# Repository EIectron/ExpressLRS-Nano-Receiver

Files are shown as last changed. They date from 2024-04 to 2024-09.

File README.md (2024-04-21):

<div align="center">
  <b>
   <h1>
      ExpressLRS micro
   </h1>
   <h6>
     V1
   </h6>
  </b>

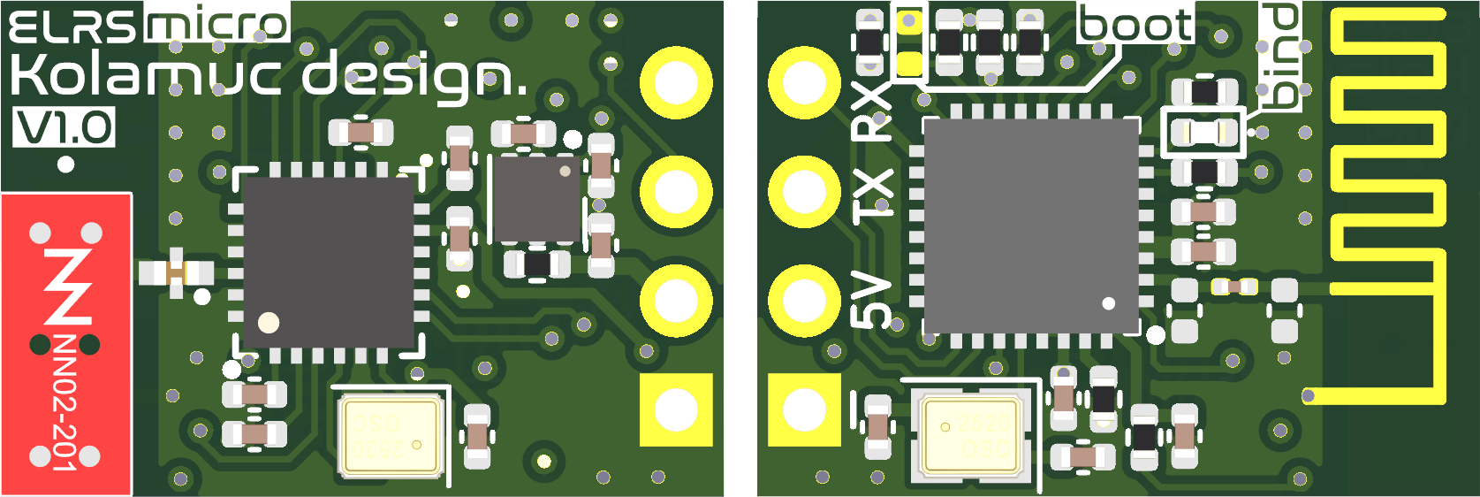
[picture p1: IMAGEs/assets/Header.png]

</div>

*Features*
* **Size**: 17x12mm
* **Gain**: 3.2dBi
* **Radio Efficiency**: >80%
* **Recommend Drone**: Whoop Drone
* **Range**: About 600 meters
* **Input voltage**: 5V
* **MCU**: ESP8285
* **Antenna**: Integrated SMD ceramic antenna
* **Frequency bands (Nano receiver 2.4G version)**: 2.4GHz ISM
* **Telemetry power**: 17mW
* *`DIY_2400_RX_ESP8285_SX1280_via_UART`*

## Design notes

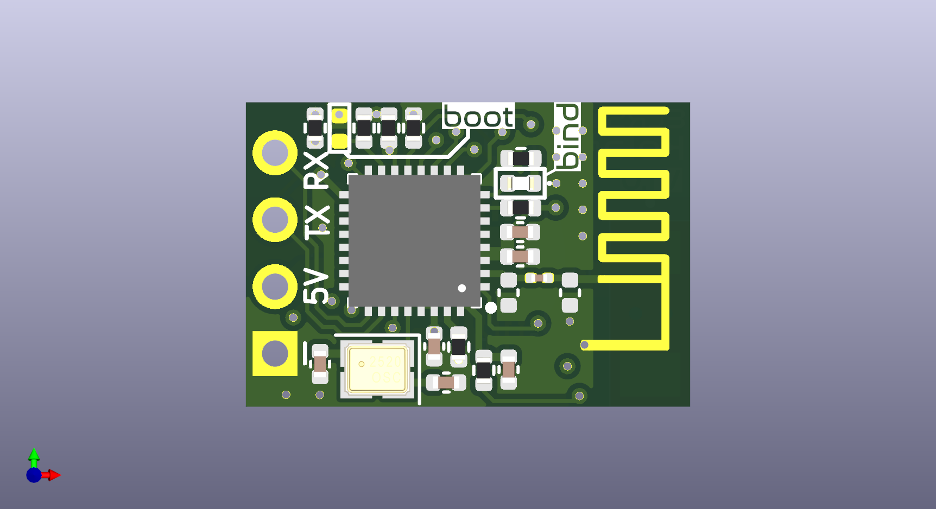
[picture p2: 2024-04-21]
IMAGEs/ExpressLRS-Nano-Receiver2.png

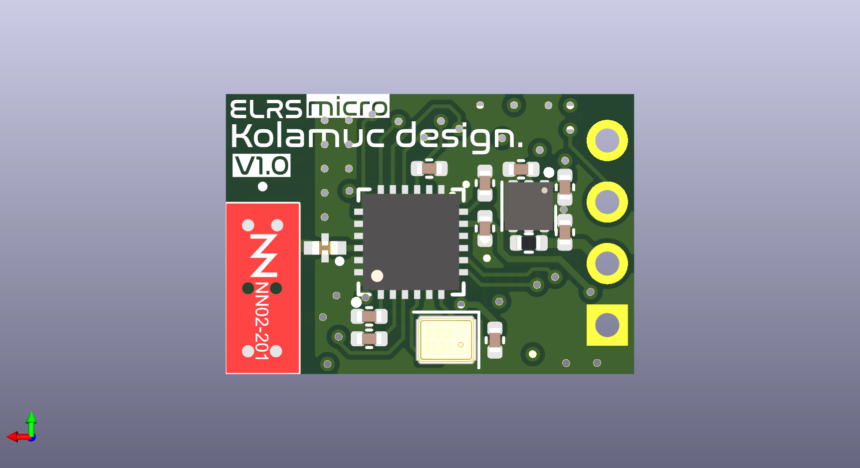
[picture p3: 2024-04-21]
IMAGEs/ExpressLRS-Nano-Receiver.png

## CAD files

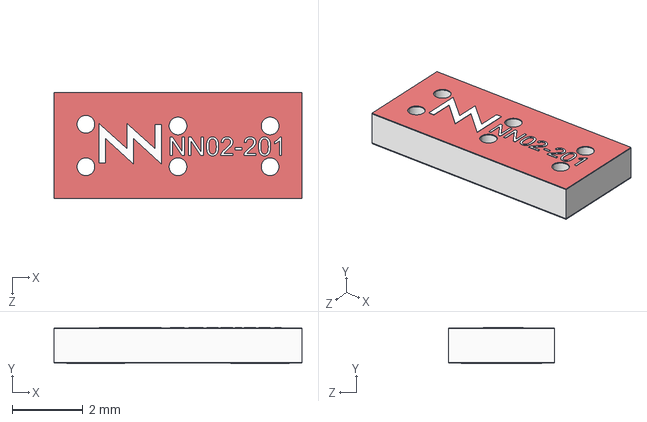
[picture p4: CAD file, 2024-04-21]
3D/NN02-201.step
7.00 x 1.02 x 3.00 mm

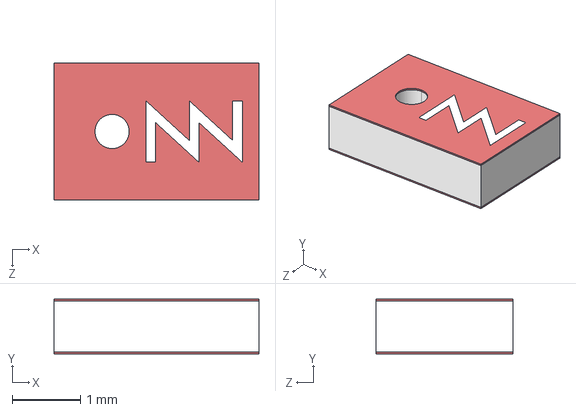
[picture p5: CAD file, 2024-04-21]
3D/NN02-101.step
3.00 x 0.8 x 2.00 mm

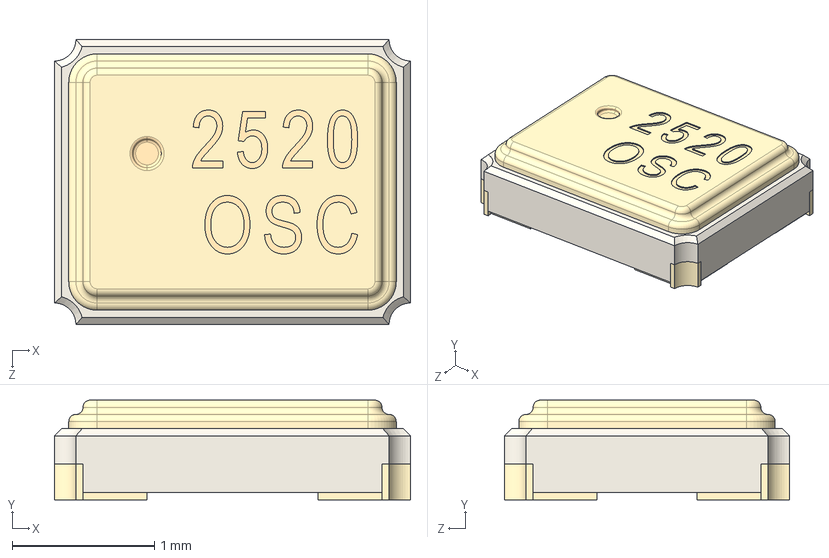
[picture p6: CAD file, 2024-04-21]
3D/2520 SMD Crystal Oscillator.STEP
2.50 x 0.7 x 2.00 mm

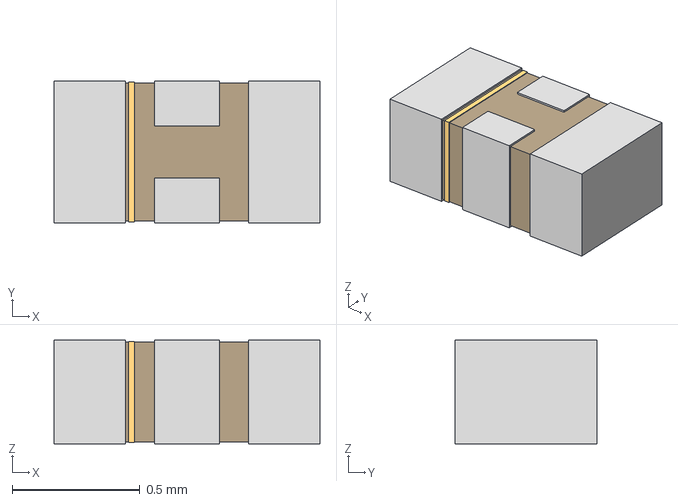
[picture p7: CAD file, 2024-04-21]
3D/2450FM07A0035T_JOT.step
1.04 x 0.558 x 0.406 mm

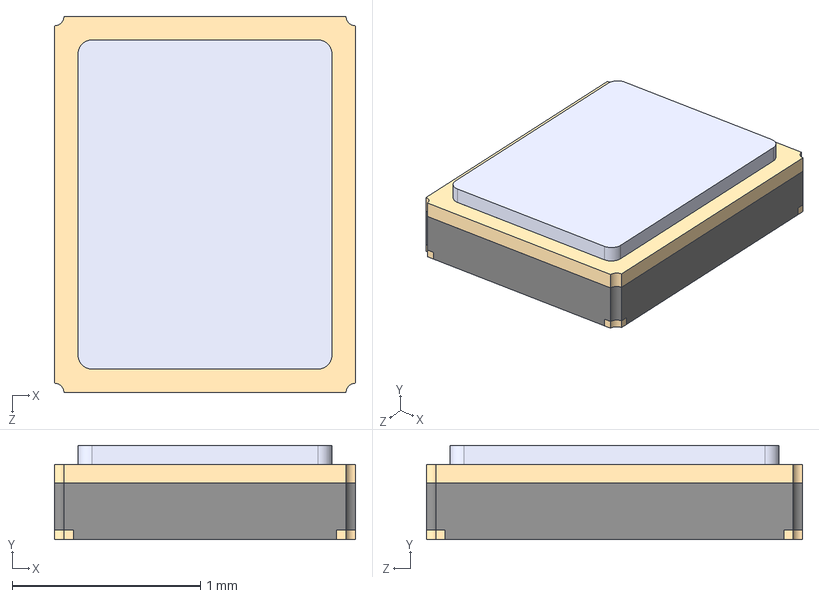
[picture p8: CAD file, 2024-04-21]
3D/ECS-320-6-37B2-CKY-TR.STEP
1.60 x 0.5 x 2.00 mm

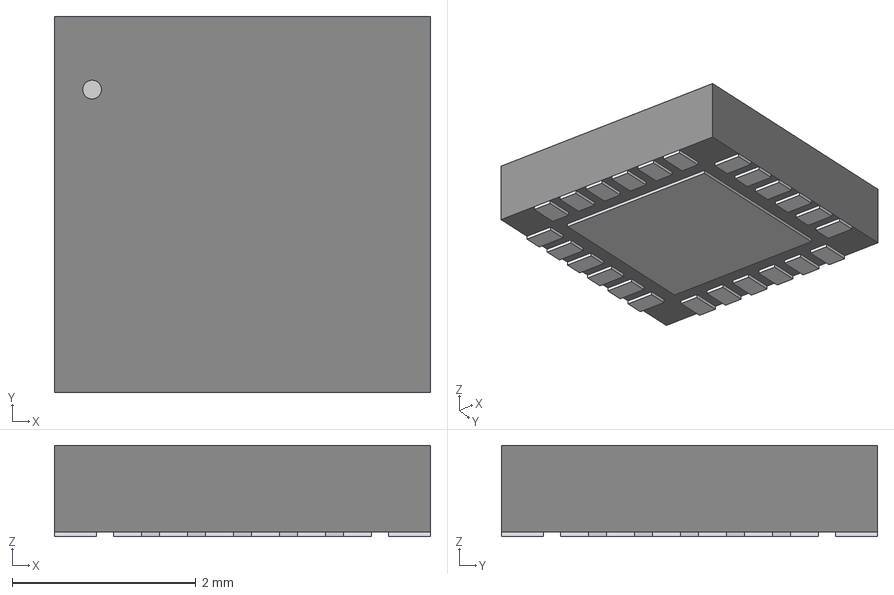
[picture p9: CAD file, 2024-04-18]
3D/QFN24_4X4_SEM.step
4.09 x 4.09 x 0.993 mm

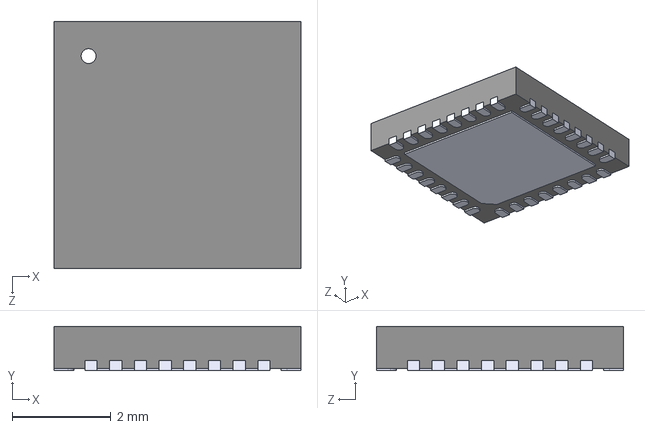
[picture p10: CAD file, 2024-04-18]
3D/ESP8285.step
5.00 x 0.9 x 5.00 mm

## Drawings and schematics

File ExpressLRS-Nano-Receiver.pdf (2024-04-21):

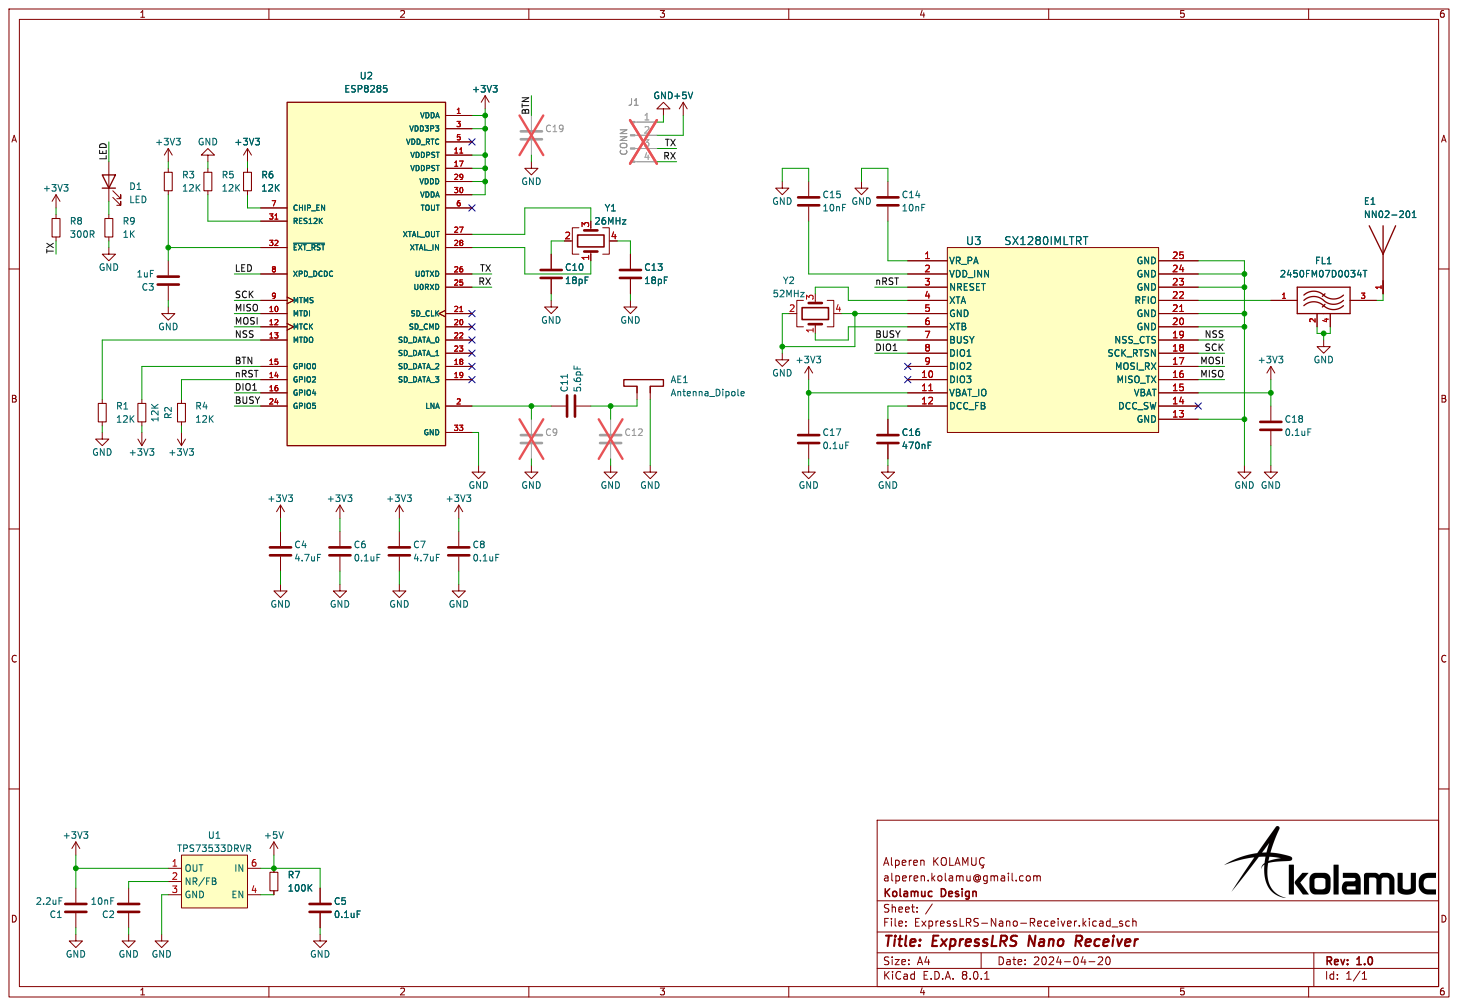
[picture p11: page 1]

LED
SCK NSS
nRST MOSI BTN MISO

Alperen þÿKOLAMUÇ alperen.kolamu@gmail.com

Design Id: 1/1 Title: ExpressLRS Nano Receiver File: ExpressLRS-Nano-Receiver.kicad_sch Sheet: / Kolamuc

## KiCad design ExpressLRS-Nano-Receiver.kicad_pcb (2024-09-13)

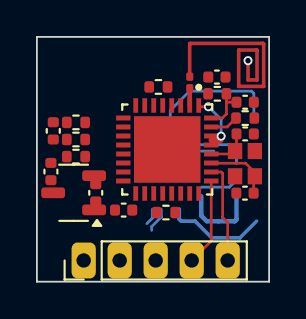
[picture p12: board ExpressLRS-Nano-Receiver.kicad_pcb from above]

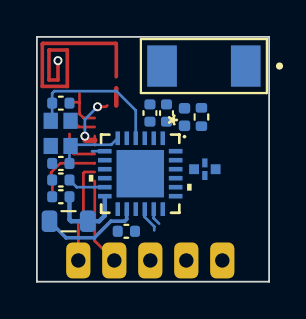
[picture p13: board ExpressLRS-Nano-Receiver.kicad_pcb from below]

Board: 4 copper layers, 12.9 x 13.6 mm, 34 parts (14 on the bottom side), 28 nets.

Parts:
C1: 470nF; C_0402_1005Metric
C2, C5, C10, C13: 18pF; C_0402_1005Metric
C3: 1uF; C_0402_1005Metric
C4: 4.7uF; C_0402_1005Metric
C6, C8, C17, C18: 0.1uF; C_0402_1005Metric
C11: 5.6pF; C_0201_0603Metric
C14, C15: 10nF; C_0402_1005Metric
C20, C21: 2.2uF; C_0402_1005Metric
D1: LED; LED_0402_1005Metric
E1: NN02-201; XCVR_NN02-201
FL1: 2450FM07D0034T; FIL_2450FM07D0034T
J1: Conn_01x05_Pin; PinHeader_1x05_P2.00mm_Vertical
L1: 15uH; L_0805_2012Metric
R1, R2, R3, R4, R5, R6: 12K; R_0402_1005Metric
R8: 300R; R_0402_1005Metric
R9: 1K; R_0402_1005Metric
U2: ESP8285; VQFN-32
U3: SX1280IMLTRT; QFN24_4X4_SEM
U4: AP2210N-3.3TRG1; SOT-23-3
Y1: 26MHz; Crystal_SMD_2016-4Pin_2.0x1.6mm
Y2: 52MHz; Crystal_SMD_2016-4Pin_2.0x1.6mm

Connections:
+3V3: C4.1, C6.1, C8.1, C17.1, C18.1, C21.1, R2.2, R3.2, R4.1, R6.1, R8.2, U2.1 (VDDA), U2.3 (VDD3P3), U2.4 (VDD3P3), U2.11 (VDDPST), U2.17 (VDDPST), U2.29 (VDDD), U2.30 (VDDA), U3.11 (VBAT_IO), U3.15 (VBAT), U4.2 (VOUT)
+5V: C20.2, J1.3, U4.3 (VIN)
/BTN: J1.1, R2.1, U2.15 (GPIO0)
/BUSY: U2.24 (GPIO5), U3.7 (BUSY)
/DIO1: U2.16 (GPIO4), U3.8 (DIO1)
/LED: D1.2 (A), U2.8 (XPD_DCDC)
/MISO: U2.10 (MTDI), U3.16 (MISO_TX)
/MOSI: U2.12 (MTCK), U3.17 (MOSI_RX)
/NSS: R1.2, U2.13 (MTDO), U3.19 (NSS_CTS)
/RX: J1.4, U2.25 (U0RXD)
/SCK: U2.9 (MTMS), U3.18 (SCK_RTSN)
/TX: J1.5, R8.1, U2.26 (U0TXD)
/V_DCC: C1.1, C15.2, L1.1, U3.2 (VDD_INN), U3.12 (DCC_FB)
/V_DCC2: L1.2, U3.14 (DCC_SW)
/nRST: R4.2, U2.14 (GPIO2), U3.3 (NRESET)
GND: C1.2, C2.1, C3.1, C4.2, C5.1, C6.2, C8.2, C10.2, C13.2, C14.1, C15.1, C17.2, C18.2, C20.1, C21.2, FL1.2, FL1.4, J1.2, R1.1, R5.2, R9.1, U2.33 (GND), U3.5 (GND), U3.13 (GND), U3.20 (GND), U3.21 (GND), U3.23 (GND), U3.24 (GND), U3.25 (GND), U4.1 (GND), Y1.2, Y1.4, Y2.2, Y2.4
unnamed: D1.1 (K), R9.2
unnamed: E1.1, FL1.3
unnamed: R6.2, U2.7 (CHIP_EN)
unnamed: C11.1, U2.2 (LNA)
unnamed: R5.1, U2.31 (RES12K)
unnamed: C10.1, U2.28 (XTAL_IN), Y1.1
unnamed: C13.1, U2.27 (XTAL_OUT), Y1.3
unnamed: C3.2, R3.1, U2.32 (~EXT_RST)
unnamed: FL1.1, U3.22 (RFIO)
unnamed: C14.2, U3.1 (VR_PA)
unnamed: C2.2, U3.4 (XTA), Y2.3
unnamed: C5.2, U3.6 (XTB), Y2.1
